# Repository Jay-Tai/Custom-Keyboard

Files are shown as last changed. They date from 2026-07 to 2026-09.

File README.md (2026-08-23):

# The Megaboard
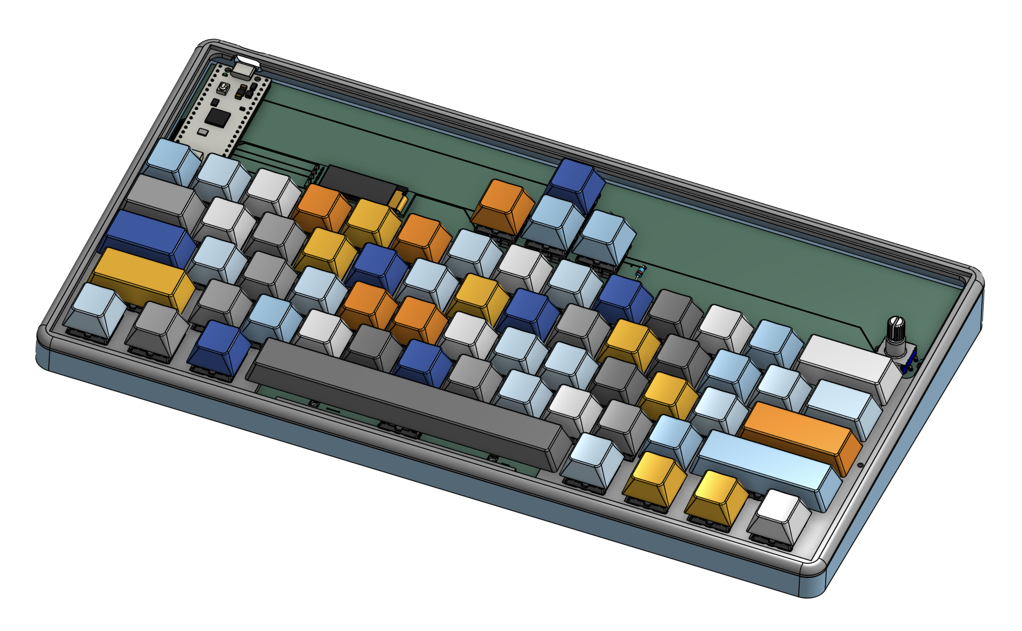
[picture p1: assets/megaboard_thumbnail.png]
The Megaboard!

The megaboard is a custom 60% keyboard that has 65 keys in total, and has many unique functions that truly make this project a one-of-the-kind.

I built this project to participate in [Hack Club's Stardance](http://stardance.hackclub.com/), and fell in love with the development of keyboards very quickly after I started!
## Features
- Amazing 3D printed case
- 0.91" OLED for animations, startup, and for other tools, such as WPM, and Caps Lock
- SK6812 Mini-E LEDs for under-key glow
- EC11 Rotary Encoder to control volume, scroll through pages, or press down to mute/unmute your zoom meeting
- 65 Akko V3 Cream Yellow Pro keys for your satisfying typing experience needs :D (Cheap and sounds like heaven)
- Topographic look all-around (Part of the PCB is exposed)
w
## CAD Model
All the parts of this project fit together using 2 m2.5 screws.
It has 2 seperate printed pirces, one to be the main base, and the other one to cover the electronics.
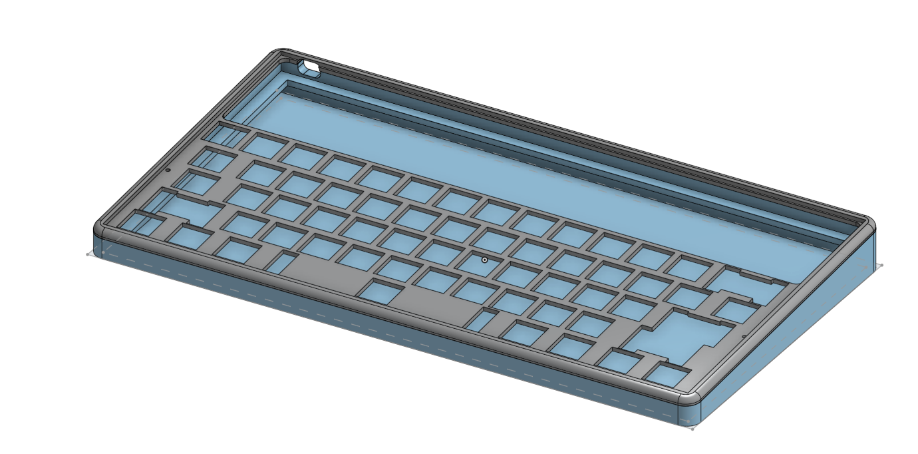
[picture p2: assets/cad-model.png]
Cad Model

Made in OnShape.

## PCB
Here's my PCB! it was made in KiCad. Some footprints and schematics were from marbastlib. I made the silkscreen in Adobe Illustrator.
#### Here is my schematic
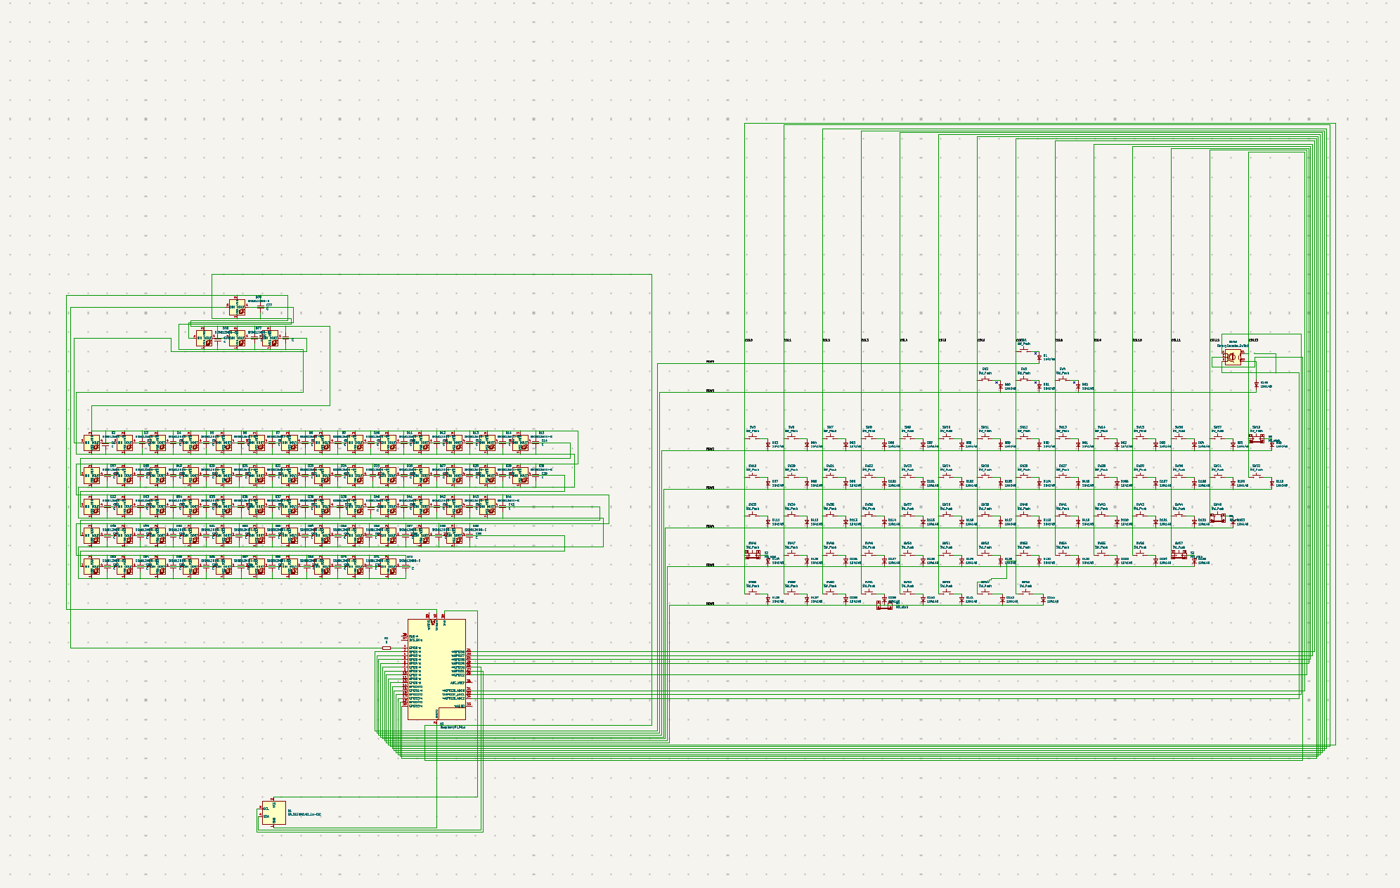
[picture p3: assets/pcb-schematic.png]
My schematic!

#### Here is my PCB
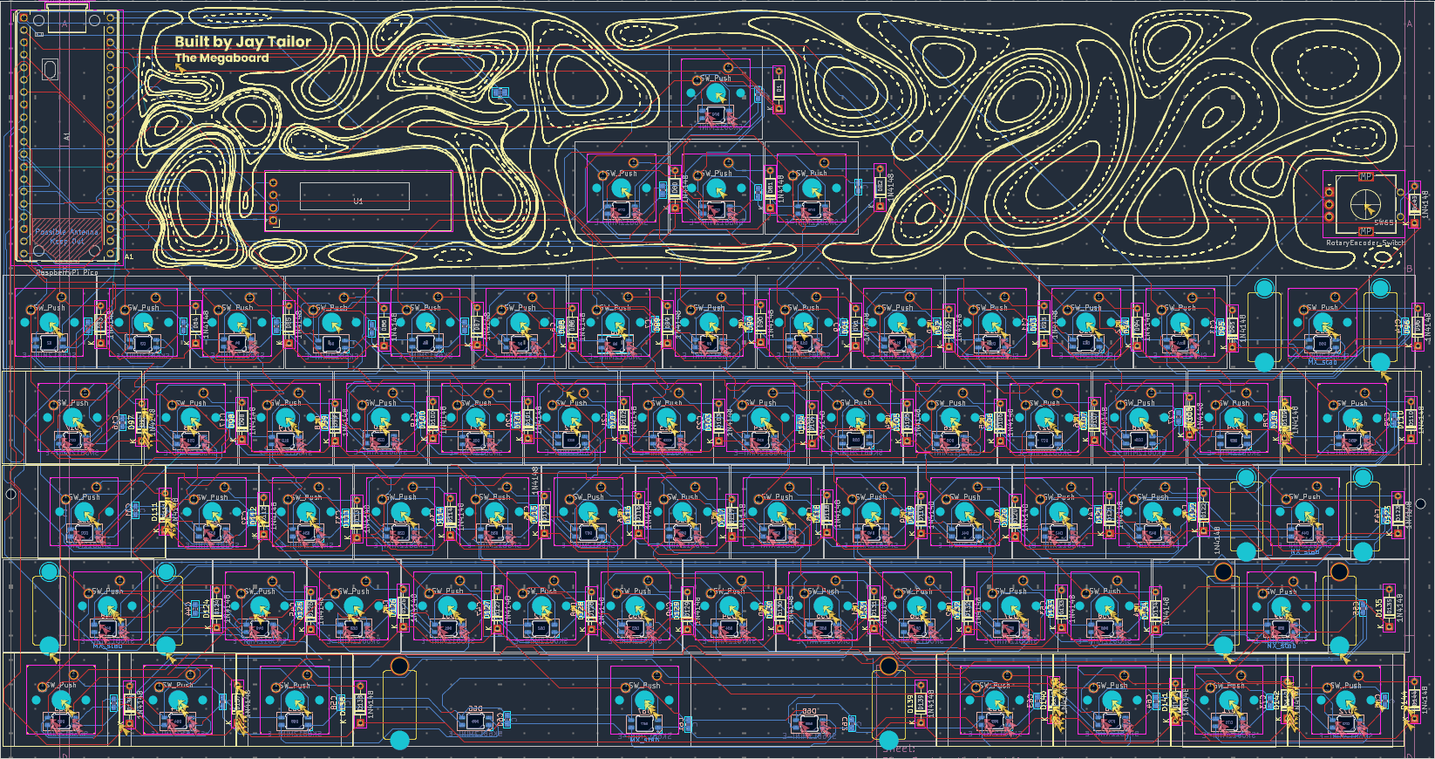
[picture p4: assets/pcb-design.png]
My PCB Design


The PCB has 2 copper layers, and all the parts that are needed are part of the PCB design. I think in retrospect, I should have moved the arrow keys to the bottom of the PCB, instead of it being at the top.

## Firmware overview
This hackpad's firmware has been designed in [QMK](https://qmk.fm/). It is a powerful, yet simple way to design keyboards that have a lot of useful functions!
- The rotary encoder controls the volume of the computer, and when you hold FN, you can scroll. When you press the encoder, it will mute/unmute your zoom call.
- The 65 keys all perform different functions that can be adjusted by simply changing it's function in keymap.c.
- The OLED starts off with a startup animation, and then after, it turns into a cat! Specifically, the Bongocat!! <b>Credits to [nwii's bongocat](https://github.com/nwii/oledbongocat) for the source code!</b>
- All keys have SK6812 Mini-E LEDs beneath them and when you press a key, its LED will light up in a reactive typing way. Take a look [here](https://youtu.be/7f3usatOIKM?t=229)!

I might add more in the future, however, that's it for now!

## BOM
Here is everything that you will need to make the megaboard:
Click [here](https://docs.google.com/spreadsheets/d/1aInlIyzgglzUiH9fcOGwBJfbiqagTssbSa5kihXWXrg/edit?usp=sharing)

## Thank you!
Thank you for taking a look! This was a huge undertaking to make this entire project, and I spent over 50 hours to make this!

Especially, thank you to [Hack Club](https://hackclub.com/) for inspiring me to make this project, and thank you to [nwii's bongocat](https://github.com/nwii/oledbongocat) animation for part of the OLED!

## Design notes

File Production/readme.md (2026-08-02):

# Production files
These are the production files!

The production files are what you need to make your own megaboard!

## Legend
- Top.step is the top part of the shell
- Bottom.step is the bottom part of the shell
- Firmware.uf2 is the firmware of the keyboard!\
- Gerbers.zip is the gerber files to submit to your PCB fab

## Note regarding gerbers
To get the results that the original megaboard looks like, change the PCB color to black.

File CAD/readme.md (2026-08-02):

# CAD

This is my CAD file! It was made on Onshape, and you can see the onshape file [here](https://cad.onshape.com/documents/f72fa77c2f5ca639697d7ad2/w/c788aea54bc0ac7d58691022/e/f66b60b9cfee9ae31c44548f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)

The file that is in this folder is the shell when it is all attached. However, the .step files for the top and bottom can be found under the production folder.

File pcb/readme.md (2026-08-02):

# PCB Files
The following files are all KiCad files. Download all the files and put them in a folder, and put it in KiCad to edit the PCB!

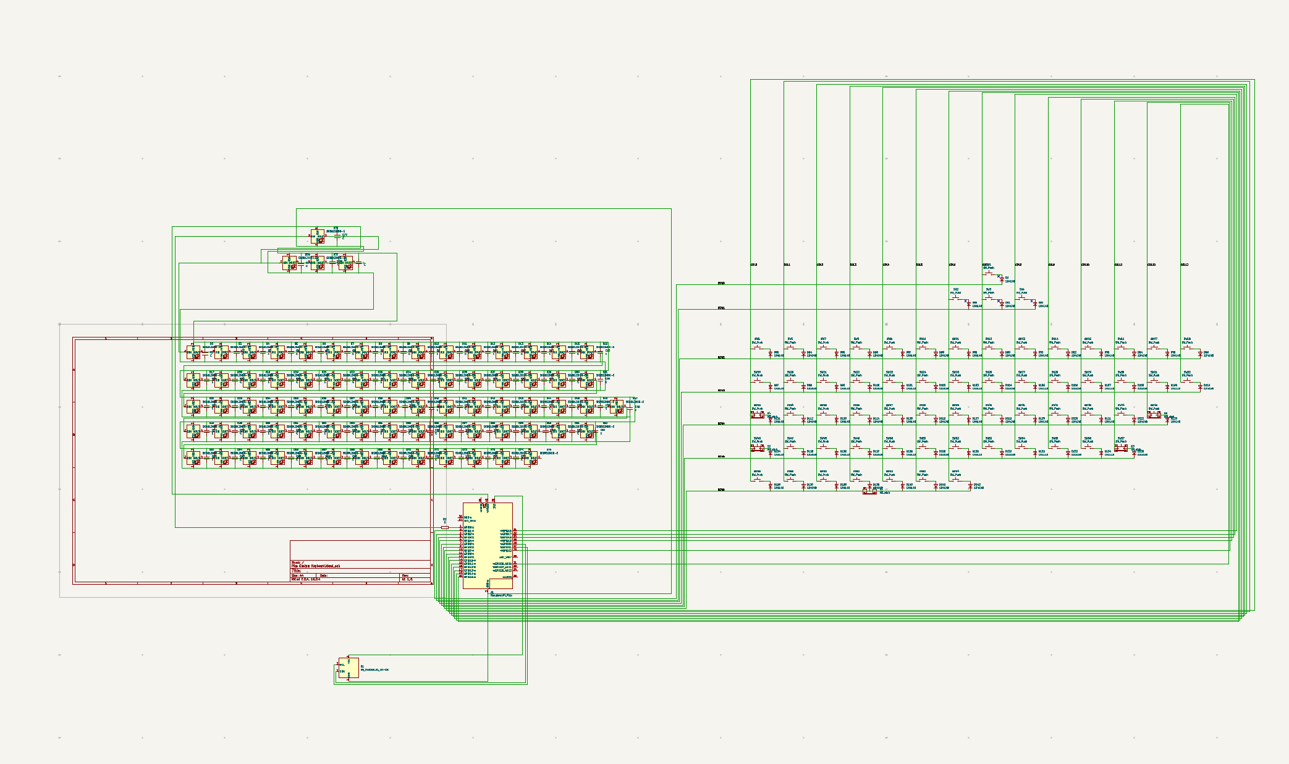
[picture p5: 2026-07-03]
journaling/major updates/schematic/Screenshot.jpg

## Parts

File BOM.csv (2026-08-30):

Item | Description | Quantity | Item Total Price + Tax | Supplier | URL
Akko V3 Cream Yellow Pro | Switches | 2 sets | $43.59 | Akkogear | https://akkogear.eu/checkouts/cn/hWNFC9Zx8n0qdDLtnQizb7BJ/en-ca
Raspberry Pi Pico SC0915 | MCU | 1 | $15.06 | PiShop | https://www.pishop.ca/product/raspberry-pi-pico-non-wireless/?src=raspberrypi
Topographic MX Keycaps | RGB Keycap | 1 set | $11.00 | Aliexpress | https://www.aliexpress.com/item/1005010637419371.html
EC11 Rotary Encoder | Rotary Encoder/Knob | 1 | $2.17 | Digikey | https://www.digikey.ca/en/products/detail/bourns-inc/PEC11R-4220F-S0024/4499660
SSD1306 OLED Display 128x32 | OLED Display | 1 | $1.15 | Aliexpress | https://www.aliexpress.com/item/1005009260655146.html
4x 2u + 1x 6.25u Cherry MX Stabilizer | Key stabilizers | 1 set | $10.02 | Aliexpress | https://www.aliexpress.com/item/1005011961905061.html
Megaboard PCB Printing with JLCPCB | PCB | 5 (Minimum order quantity) | $56.32 | JLCPCB | https://i.ibb.co/LhSh1BdN/Screenshot-2026-08-02-at-12-04-04-PM.png (Screenshot)
SK6812 Mini E-LEDs | RGB LED | 70 | $5.14 | LCSC Electronics | https://www.lcsc.com/product-image/C5149201.html?whichImg=sch
0805 100PF 50V Capacitor | Per-LED Capacitor | 1 | $1.04 | Aliexpress | https://www.aliexpress.com/item/1005007123309391.html
1N4148 Diode | Per-Switch Diode | 65 | $2.11 | Digikey | https://www.digikey.ca/en/products/detail/onsemi/1N4148/458603
M2.5x16mm 50pcs Screw Set | Shell fastener | 1 Set | $7.33 | Aliexpress | https://www.aliexpress.com/item/1005004410362290.html
330 Ohm Resistor | Resistor | 1 | $0.13 | Digikey | https://www.digikey.ca/en/products/detail/stackpole-electronics-inc/CF14JT330R/1741399
Printing Legion Fee - Hack Club 3DP Service | Printing shell | 1 | $15.00 | Hack Club
Digikey International Shipping Fee | Shipping | 1 | $16.14 | Digikey | https://i.ibb.co/r2WyLzsk/Screenshot-2026-08-02-at-12-36-13-PM.png (Screenshot)
Grand total | $186.19 |  | Please note that all costs are listed in US Dollars (USD), and all shipping costs are included in the item price, unless specified when bolded, in which, the shipping costs are italicized

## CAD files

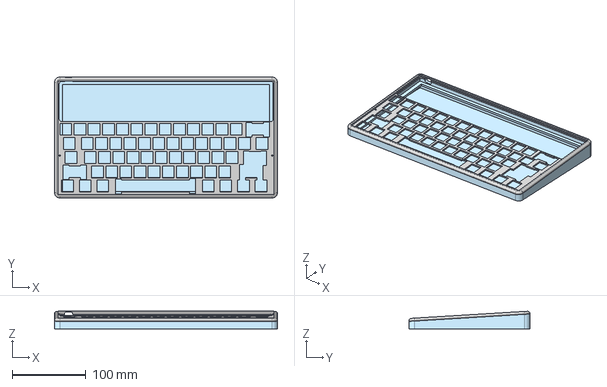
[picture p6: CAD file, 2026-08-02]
CAD/shell.step
302.4 x 164.0 x 23.8 mm

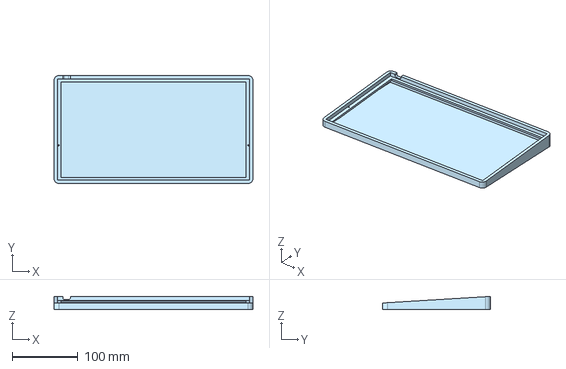
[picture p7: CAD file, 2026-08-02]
Production/Bottom.step
302.4 x 164.0 x 20.0 mm

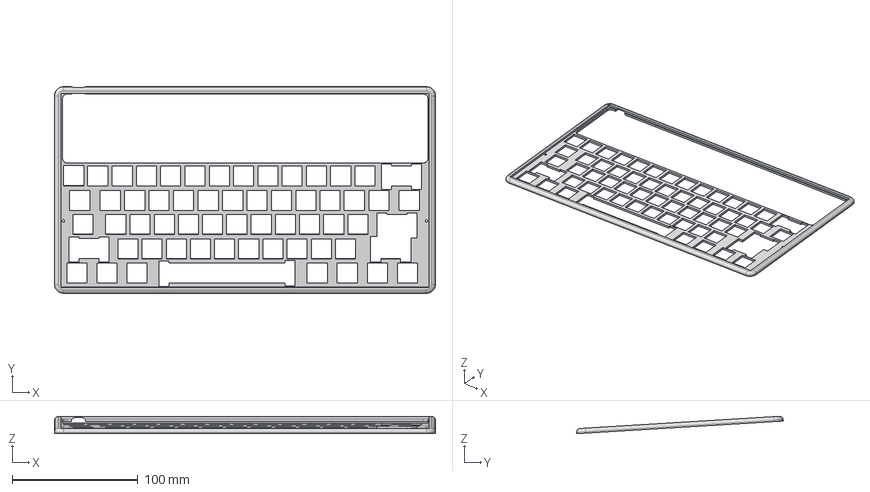
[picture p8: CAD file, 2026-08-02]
Production/Top.step
302.4 x 164.0 x 13.8 mm

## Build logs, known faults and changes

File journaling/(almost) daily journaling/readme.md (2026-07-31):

# My (Almost) daily journaling
This is the journaling that I have been keeping track of!

Please note that <b>my journal entries were originally stored on fallout, and have been imported since</b>.

The folder names are the dates of the journal entries.

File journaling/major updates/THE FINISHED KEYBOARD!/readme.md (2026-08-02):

# The final keyboard! (WOOOOOO)
The keyboard is finally finished!

I spent around 60 hours on it (Some time hasn't been logged as I forgot to click record, however, over 50 hours have been logged), and it is finally finished!

Here is what the keyboard will look like when I make it:
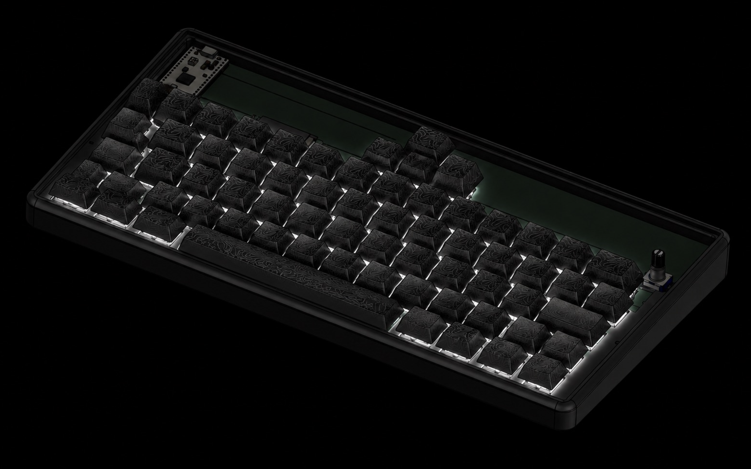
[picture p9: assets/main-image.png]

Please note that the image is an AI-Generated image, but is accurate on what the actual keyboard will look like (Only the key labels and the top PCB silkscreen is missing)

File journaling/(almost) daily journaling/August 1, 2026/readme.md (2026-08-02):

<p><b>Started the BOM!</b></p>
<p><i>1 hour and 45 mintues logged</i></p>

Today, I started my BOM! I finished a good portion of it, and I am going to finish the rest tomorrow.

When I was looking at JLCPCB, the actual keyboard PCB turned out really nice in black! Take a look :)

I am going to get it in black, as part of the PCB is going to be exposed (Right before the topographic silkscreen starts to show)

See you tomorrow!

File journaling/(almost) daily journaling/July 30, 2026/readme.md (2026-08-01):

<p><b>Today was a somewhat productive day!</b></p>
<p><i>1 hour and 3 minutes logged</i></p>

Today was a somewhat productive day!
I managed to program the entire startup screen, and I managed to import the bongo cat's frames.


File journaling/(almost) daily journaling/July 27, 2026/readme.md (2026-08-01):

Today, I open-sourced the keyboard bongo and also made my loading screen for my OLED into the bitmaps!
Doesn't it look so cool?


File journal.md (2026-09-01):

# July 3, 2026
<p><b>My KiCad Schematic!</b></p>
<p><i>4 hours and 27 minutes logged</i></p>
<p>(Yes, it was all done in a day haha)</p>

The schematic includes all the components of my keyboard!
The keyboard includes all the correct wiring for the backlights, the switches, the Display, and the Rotary Encoder that is going to be part of the final keyboard.
I acutally got really lucky with the microcontroller - I had JUST ENOUGH ports to house all the different pins that everything in my keyboard requires.

<i>Take a look at the final shematic!</i>
<br/>
The final schematic!

Watch the timelapse here:
https://f8d710a55cb9b516d88635f103c2c9f2.r2.cloudflarestorage.com/collapse/timelapses/5871cd09-b832-4ddf-aae9-c32493282611/timelapse.mp4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

# July 4, 2026
<p><b>Assigning footprints!</b></p>
<p><i>2 hours and 3 minutes logged</i></p>

Today was a bit of a busy day for me. However, for my custom keyboard, I still managed to work on assigning my footprints!
I forgot to record part of it. Sorry! :P
I faced a bit of an error where KiCad kept on crashing every single time I tried opening the "Assign Footprints" window. I  spent around 2 hours on that!



# July 5, 2026
<p><b>Electric component layout</b></p>
<p><i>2 hours and 2 minutes logged</i></p>

Today, I worked on figuring out electrical component layout, along with placing the arrow keys + top row of my keyboard (Along with all of its electrical components, such as a Capacitor!)
Take a look at the image!



# July 6, 2026
<p><b>Finishing layout + starting wiring</b></p>
<p><i>3 hours and 32 minutes logged</i></p>

Today, I finished the layout of my entire project and started wiring! I finished the power and GND of all LEDs, and I am working on DIN and DOUT!


# July 7, 2026
<p><b>Finished wiring!</b></p>
<p><i>3 hours and 5 minutes logged</i></p>

Today, I finished up all of the wiring for my project, fixed any errors, and also finished 90% of the wiring for the switches!
Here's a quick photo of it! :D


Tomorrow, I am going to finish my PCB, and start the case!
IM SO EXCITEDDDD

# July 8, 2026
<p><b>Small update</b></p>
<p><i>1 hour and 5 minutes logged</i></p>

Today was a bit of just a small progress day. I finished the wiring, and fixed an error with my rotary encoder.



I also learnt how to make silkscreens!

# July 9, 2026
<p><b>Keyboard Silkscreen Work</b></p>
<p><i>1 hour and 3 minutes logged</i></p>

Today, I worked on the keyboard's Silkscreen! I am making a topographic layer, and I finished the rough idea of how it will look like!
Tomorrow, I will be cleaning up the effect, and then adding it to my project!
This is what the silkscreen looks like so far! :D



# July 11, 2026
<p><b>Finished the PCB!</b></p>
<p><i>5 hours and 36 minutes logged</i></p>

Today, I finished my PCB!
I worked on the silkscreen and made that the rest of the PCB was in function



# July 12, 2026
<p><b>Starting the CAD!</b></p>
<p><i>1 hour and 17 minutes logged</i></p>

Today, I started the CAD! I didn't get far, as I was getting very distracted, and still getting in the jist of things. In addition, I also wasn't at home or at my computer for a long portion of today.


# July 13, 2026
<p><b>Fixing my PCB</b></p>
<p><i>1 hour and 45 minutes logged</i></p>

Today, I made a HUGE realization: I placed the LEDs on the wrong side of the PCB, meaning that all the LEDs need to be rewired! This is me trying to figure it out :P
How cool is this silkscreen tho? :D


# July 15, 2026
<p><b>Fixing wiring</b></p>
<p><i>1 hour and 3 minutes logged</i></p>

Today, I ended up deleting all of the previous vias I made for my PCB's lights, and ended up starting all over again. Here is a look!



# July 16, 2026
<p><b>Big breakthrough</b></p>
<p><i>1 hour and 14 minutes logged</i></p>

Today, I had to clear out all of my work again, but I learnt what vias are, and how to make them, along with making a VCC plane to help me finally finish these LEDs! I will be doing that tomorrow.
Here's a look at one of my vias that I am going to be connecting to a plane from a capacitor.



# July 17, 2026
<p><b>Finished the PCB!</b></p>
<p><i>1 hour and 4 minutes logged</i></p>

Today, I finished up my PCB! I made a ground plane, and I used the Vias that I learnt about yesterday to make clean wiring for my keyboard.
Here's what it looks like!



(The random background is the ground plane)

# July 18, 2026
<p><b>Started the CAD!</b></p>
<p><i>1 hour and 9 minutes logged</i></p>

Today, I started my CAD! I made the main base, along with a spot to put in my PCB. here's what it looks like so far! :D


# July 19, 2026
<p><b>Finished the keyboard shell!</b></p>
<p><i>1 hour and 40 minutes logged</i></p>

Today, I finished up the shell for the keyboard! This was really fun to make, and it took ~2.5 hours to make the entire thing.


# July 20, 2026
<p><b>Starting the firmware!</b></p>
<p><i>1 hour and 21 minutes logged</i></p>

Today, I started the firmware for my keyboard! I laid out all of the functions of the keys, and I programmed all of them. I also created the macro for the mute/unmute function of the rotary encoder wheToday, I started the firmware for my keyboard! I laid out all of the functions of the keys, and I programmed all of them. I also created the macro for the mute/unmute function of the rotary encoder when I press it in meetings.
Tomorrow, I will be programming the lights and the screen. From there, I am going to do the final touches, create the BOM, and then end a chapter!
Here is the code so far!


# July 21, 2026
<p><b>2nd day of my firmware!</b></p>
<p><i>1 hour and 41 minutes logged</i></p>

Today, I was writing my firmware again!
For some reason, it didn't save my work yesterday, so I redid it (For 25 minutes), and I finished the encoder and configured the lights so far!
Excited for tomorrow!


# July 22, 2026
<p><b>Transition day to rust</b></p>
<p><i>1 hour and 15 minutes logged</i></p>

Today was more of a transition day. I still worked on the firmware, but I was making the transfer from cloud RMK to rust. This meant that I had to spend time adapting my firmware from cloud to rust. That was my day today!


# July 24, 2026
<p><b>Finshing the keyboard keymap</b></p>
<p><i>1 hour and 6 minutes logged</i></p>

Today, I finished the keymap of my keyboard, and I am onto the rotary encoder! However, I am constantly facing errors, and I am pushing through that!


# July 25, 2026
<p><b>Biggest leap in firmware</b></p>
<p><i>2 hours and 26 minutes logged</i></p>

Today was the biggest leap in my firmware so far.
I found that RMK was not worth fiddling around with for so long. It's better to get another firmware that I am more used to. This is why I used QMK.
With QMK, it made it really easy to get the reactive typing feeling that I wanted. Here's a quick idea of how it will look like: https://youtu.be/7f3usatOIKM?t=229
With that idea, I switched to QMK, added all that I had before, and made the reactive typing interface! I'm really proud of the result!


# July 26, 2026
<p><b>LCD Design!</b></p>
<p><i>1 hour and 55 minutes logged</i></p>

Today, I mainly explored how to design my LCD display. I designed a concept of a loading bar when the keyboard is first plugged in (see image below), and I might open source the popular keyboard bongo!


# July 27, 2026
Today, I open-sourced the keyboard bongo and also made my loading screen for my OLED into the bitmaps!
Doesn't it look so cool?


# July 29, 2026
<p><b>JSON + Starting OLED!</b></p>
<p><i>1 hour and 6 minutes logged</i></p>

Today, I worked on my JSON, and also started the coding part for my OLED! This was a bit of a slow day, though :P


# July 30, 2026
<p><b>Today was a somewhat productive day!</b></p>
<p><i>1 hour and 3 minutes logged</i></p>

Today was a somewhat productive day!
I managed to program the entire startup screen, and I managed to import the bongo cat's frames.


# July 31, 2026
<p><b>LETS GOOOOOOOO</b></p>
<p><i>2 hours and 4 minutes logged</i></p>

Today, I FINALLY finished the code of the firmware! I went through a ton of bugs, and the code finally compiled!



From there, I also added all of the journal logs finally into my GitHub repo!

# August 1, 2026
<p><b>Started the BOM!</b></p>
<p><i>1 hour and 45 mintues logged</i></p>

Today, I started my BOM! I finished a good portion of it, and I am going to finish the rest tomorrow.

When I was looking at JLCPCB, the actual keyboard PCB turned out really nice in black! Take a look :)

I am going to get it in black, as part of the PCB is going to be exposed (Right before the topographic silkscreen starts to show)

See you tomorrow!

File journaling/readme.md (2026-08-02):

# Total time spent: 50 hours and 21 minutes logged
Please note that all of the tiem that I spent working on this project hasn't been logged. Part of the time that I spent on this I forgot to record, and with the lost logged time, I spent around 60-65 hours on this.

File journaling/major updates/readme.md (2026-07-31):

# Major Updates

Alongside with all of the journaling that I have done for this project, I have also added the most major updates! Take a look at the folders! :D

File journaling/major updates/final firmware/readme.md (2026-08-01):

# Let's GOOOOO
Today, I finished the firmware for my project! It's on QMK.

It took a long time, (The longest component of this entire project), but now that the last component is done, I am more motivated than ever to get the last small parts of the project done!
Noice

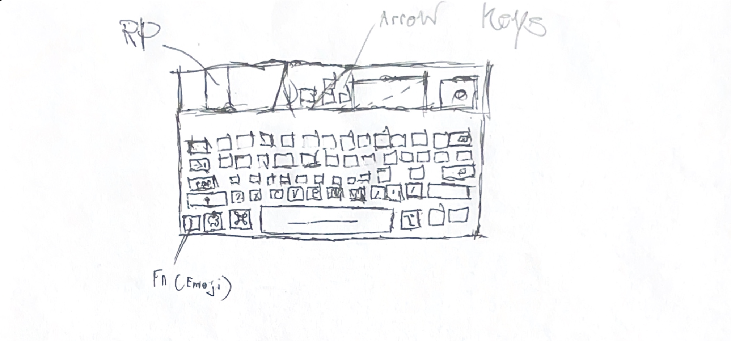
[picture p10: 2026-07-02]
journaling/major updates/sketching/Final Sketch.png

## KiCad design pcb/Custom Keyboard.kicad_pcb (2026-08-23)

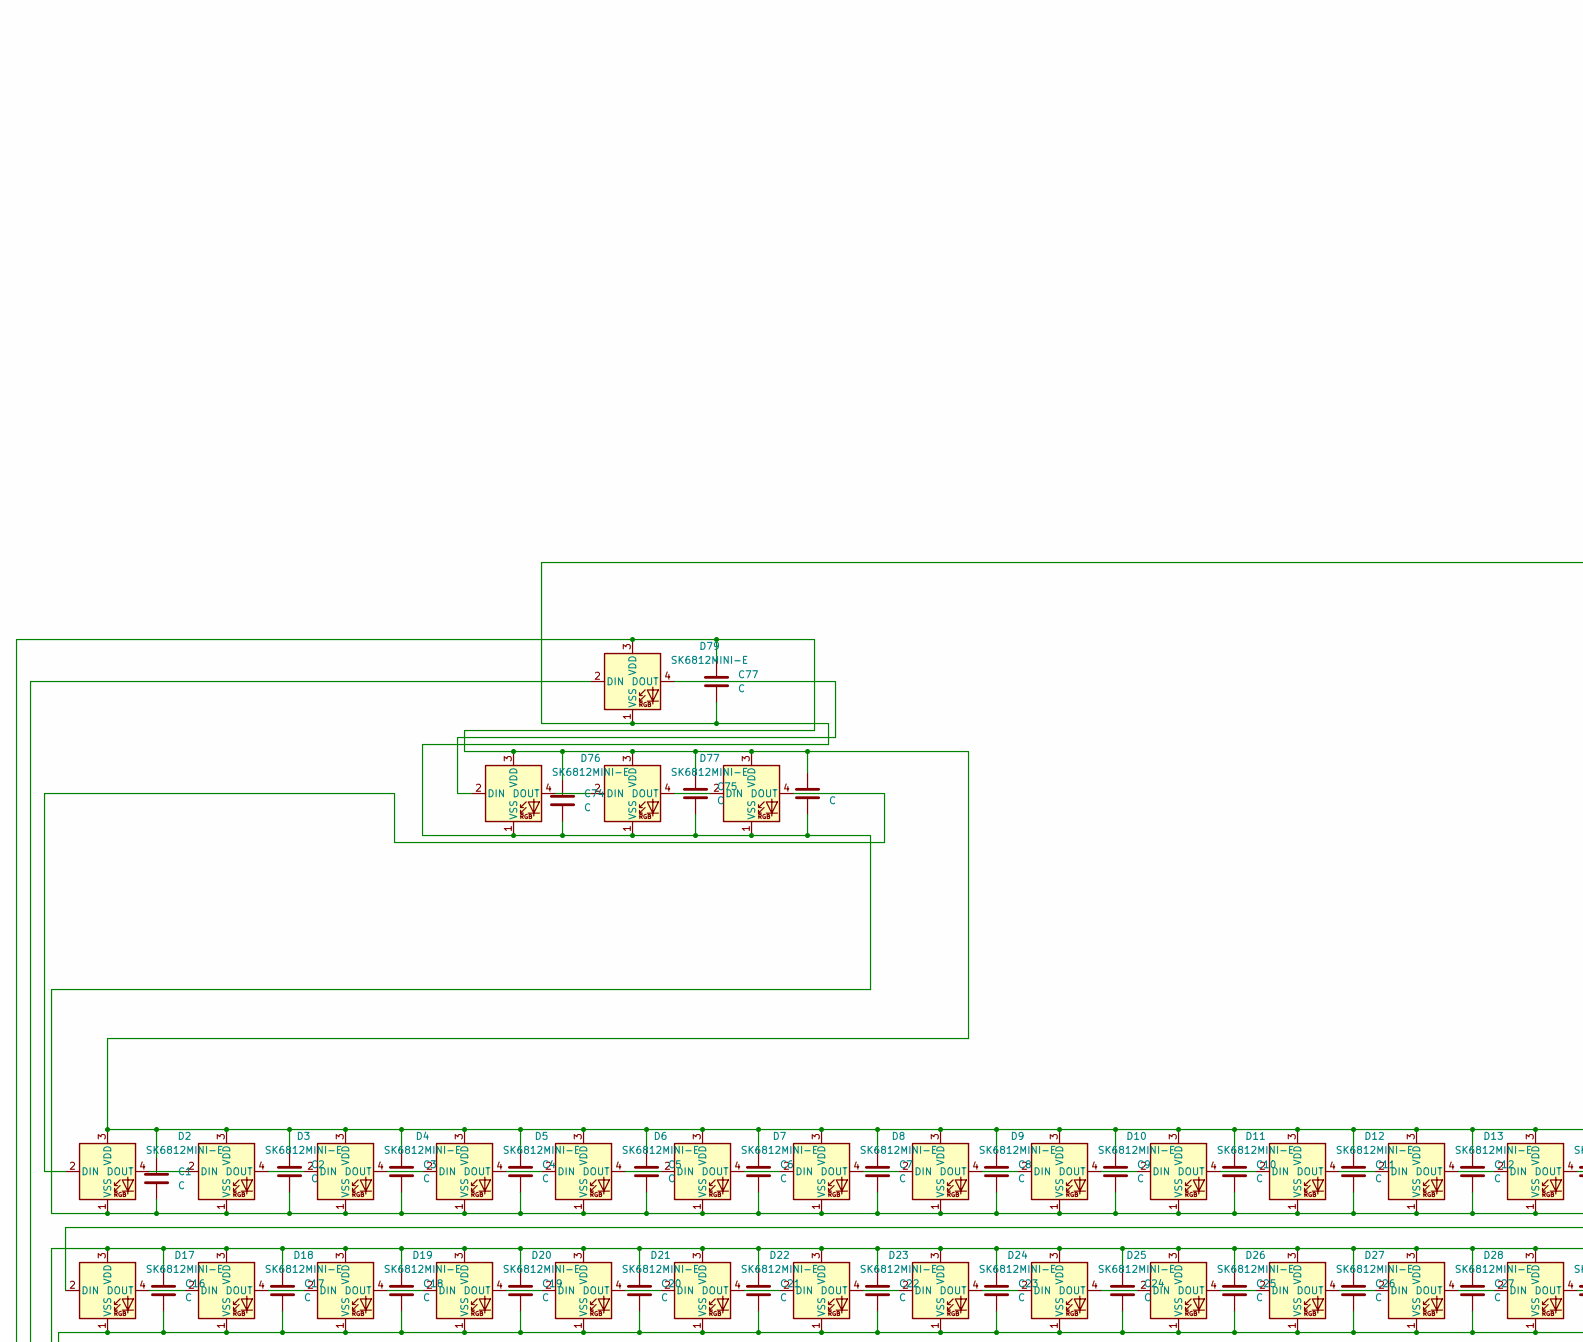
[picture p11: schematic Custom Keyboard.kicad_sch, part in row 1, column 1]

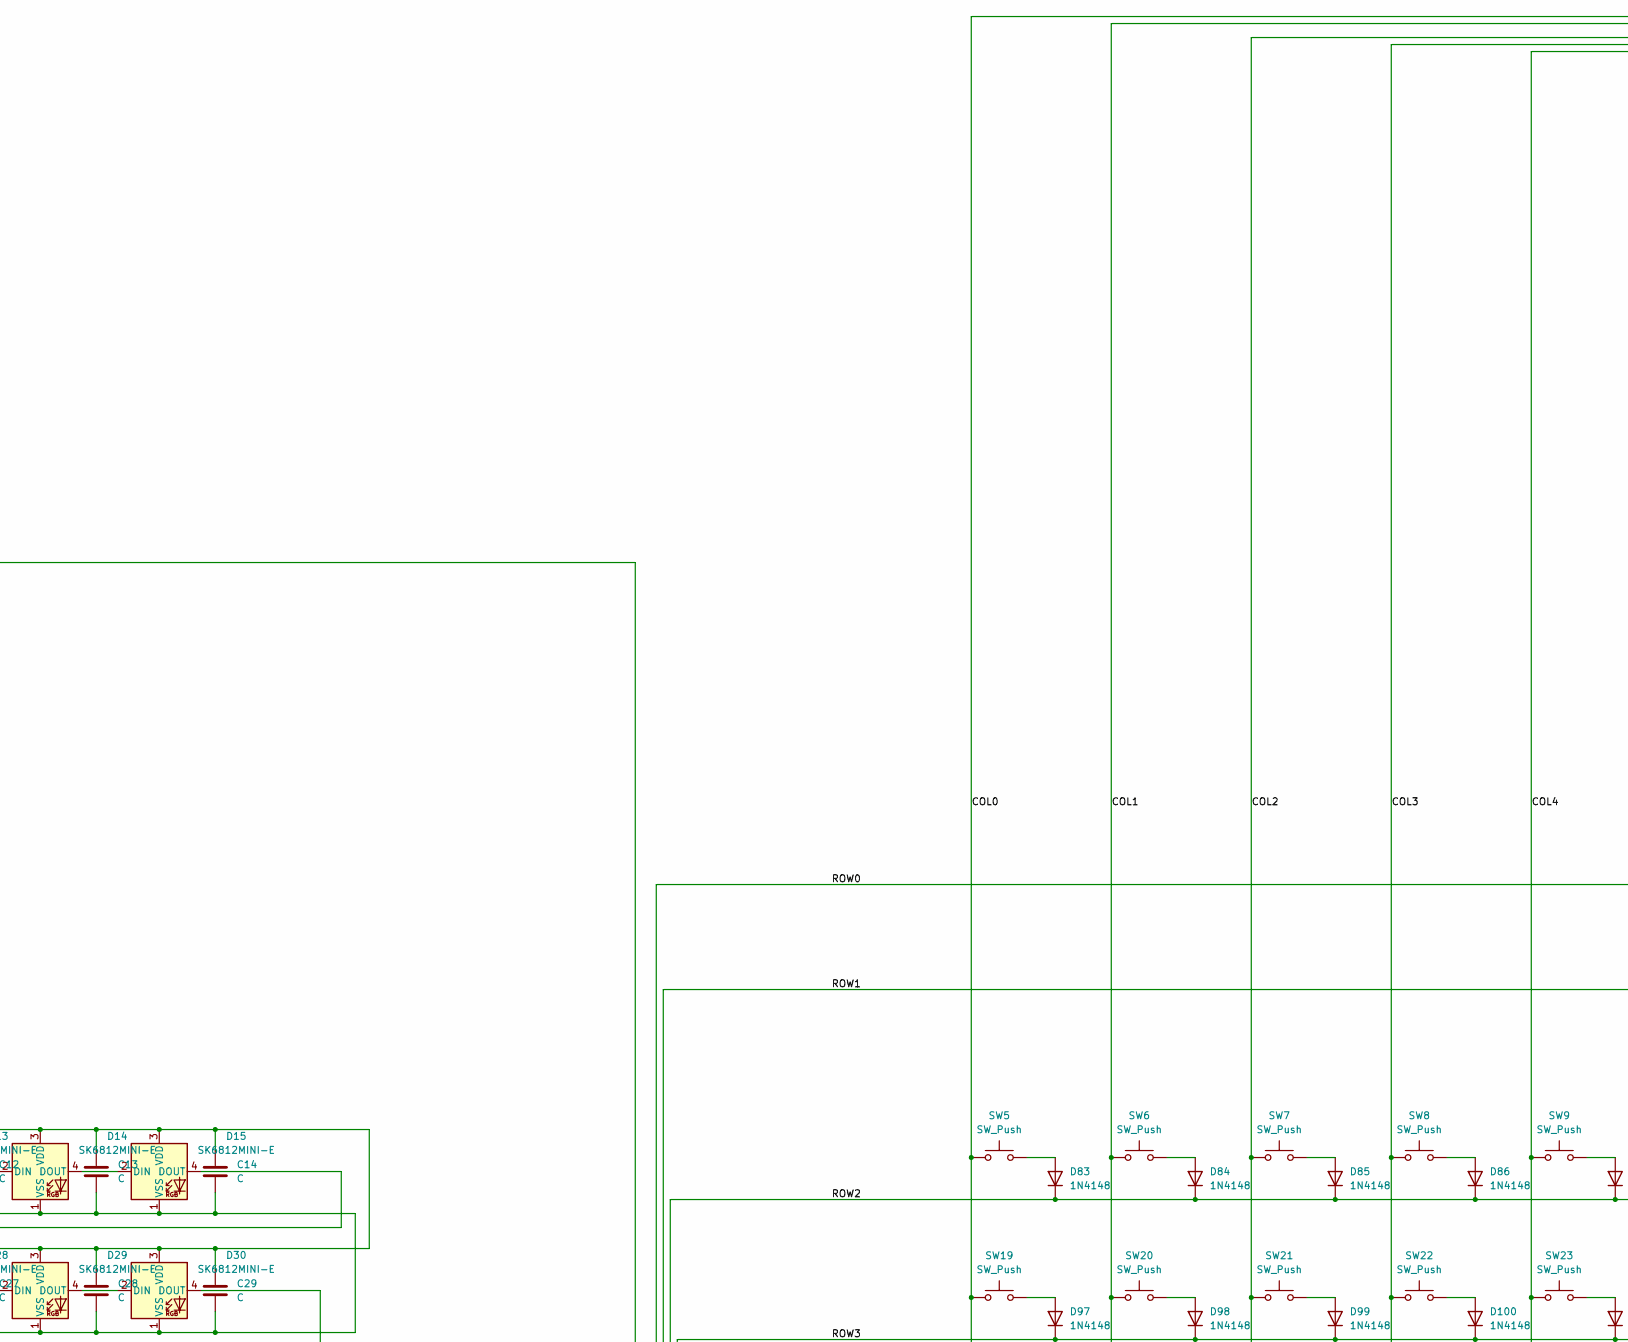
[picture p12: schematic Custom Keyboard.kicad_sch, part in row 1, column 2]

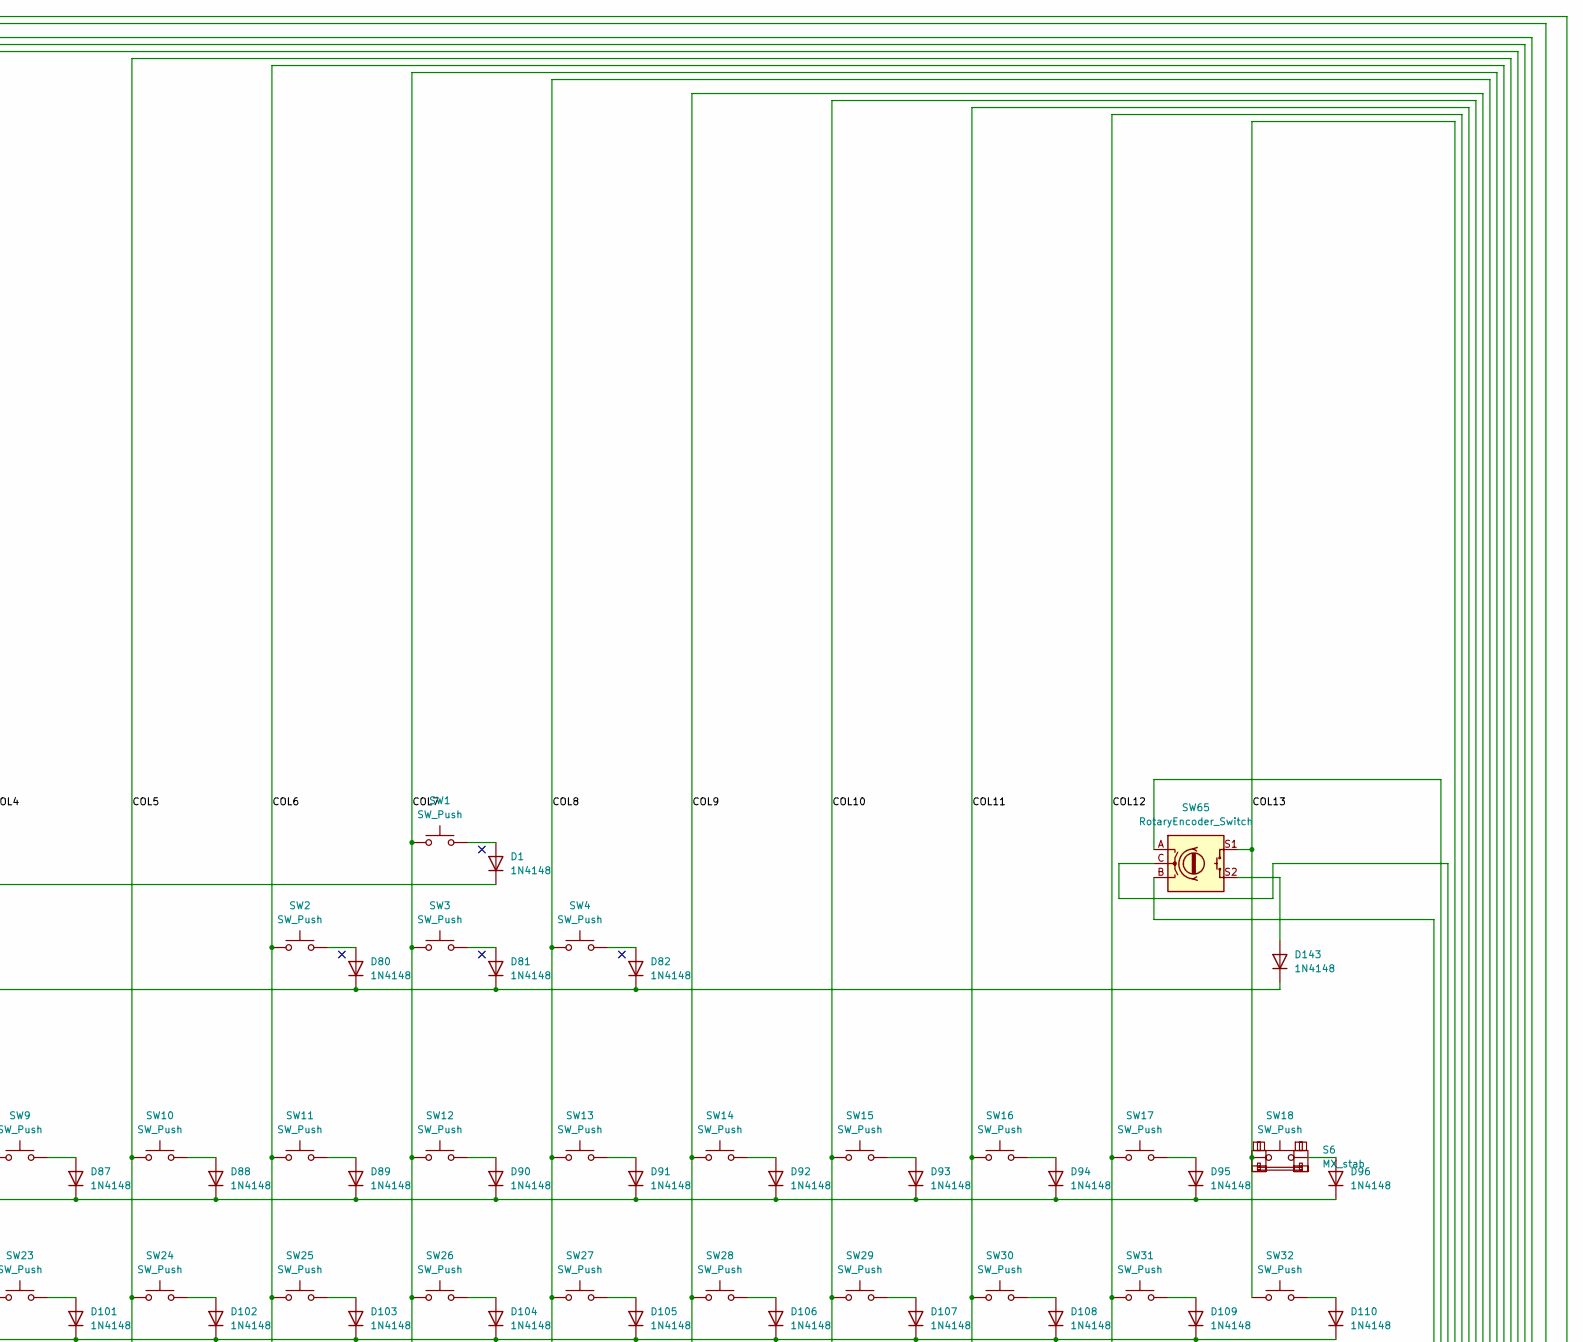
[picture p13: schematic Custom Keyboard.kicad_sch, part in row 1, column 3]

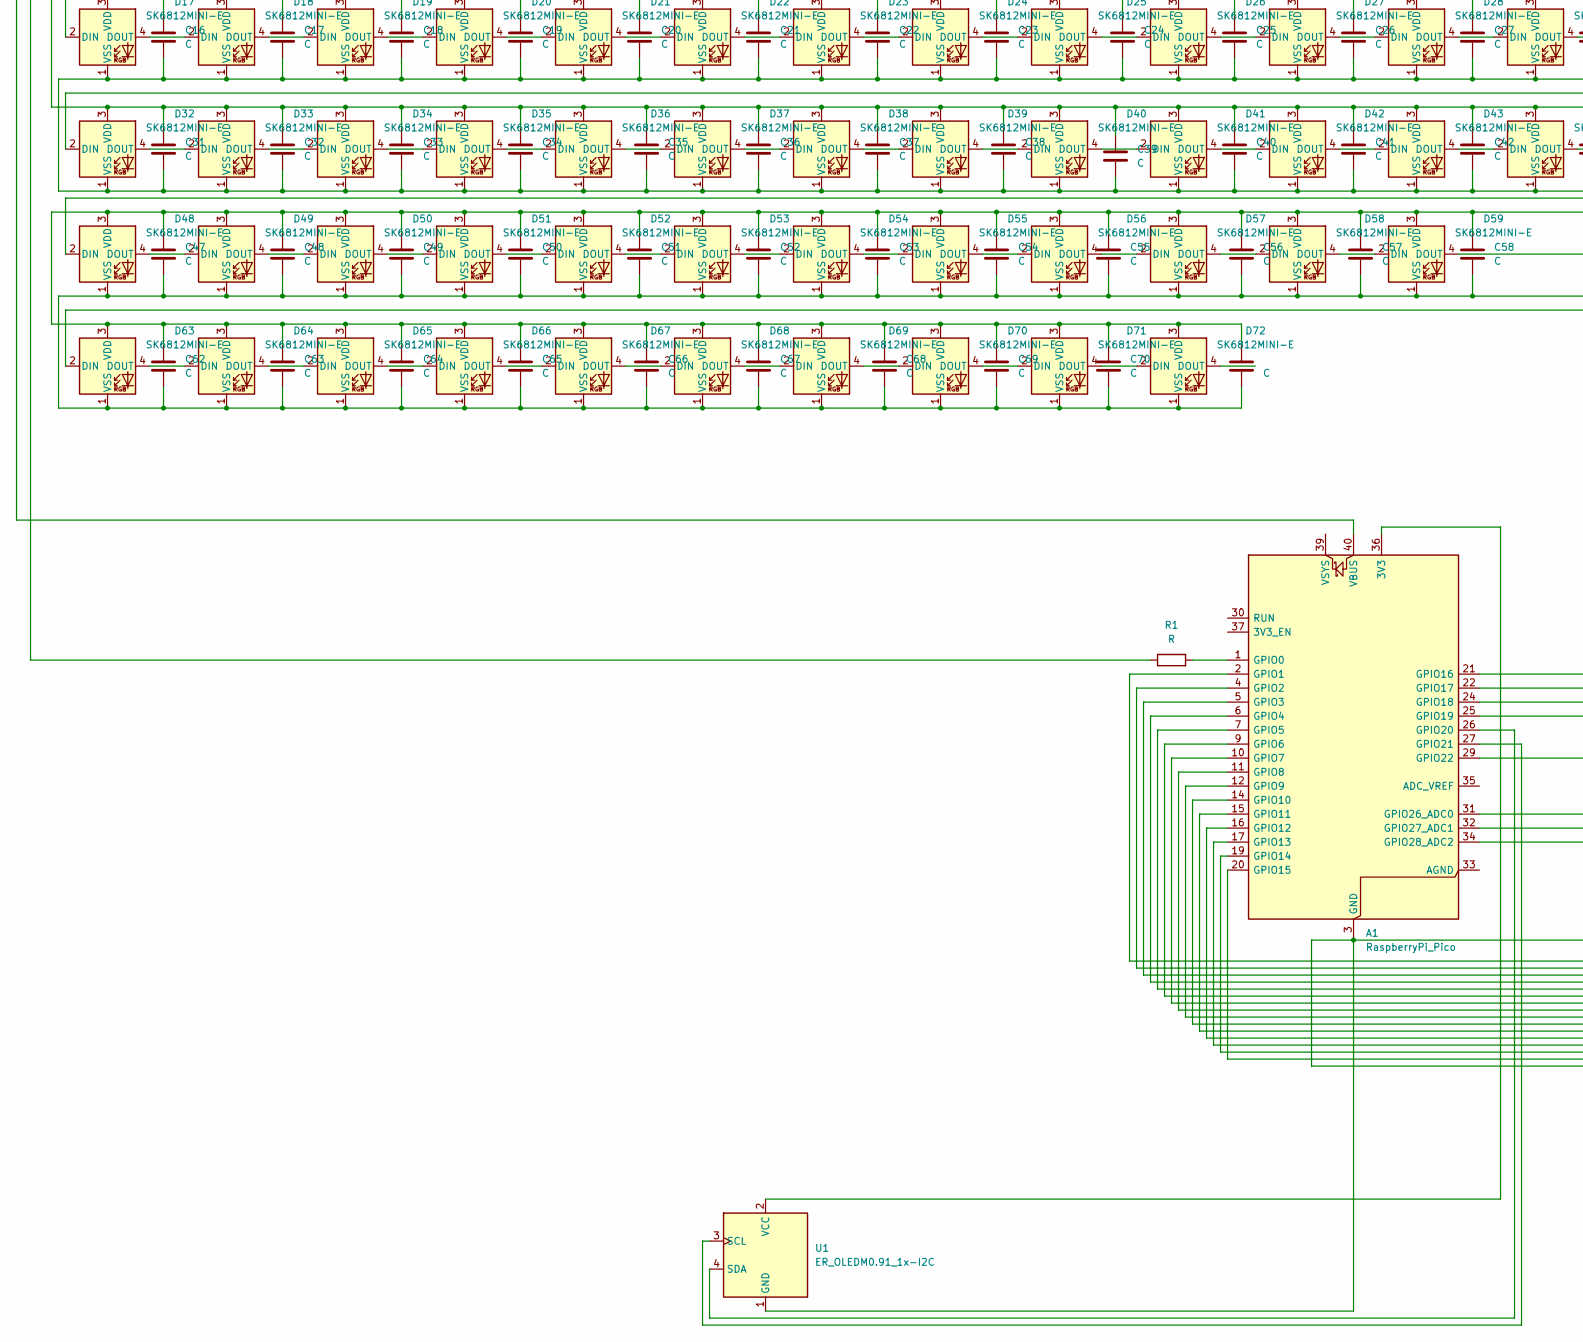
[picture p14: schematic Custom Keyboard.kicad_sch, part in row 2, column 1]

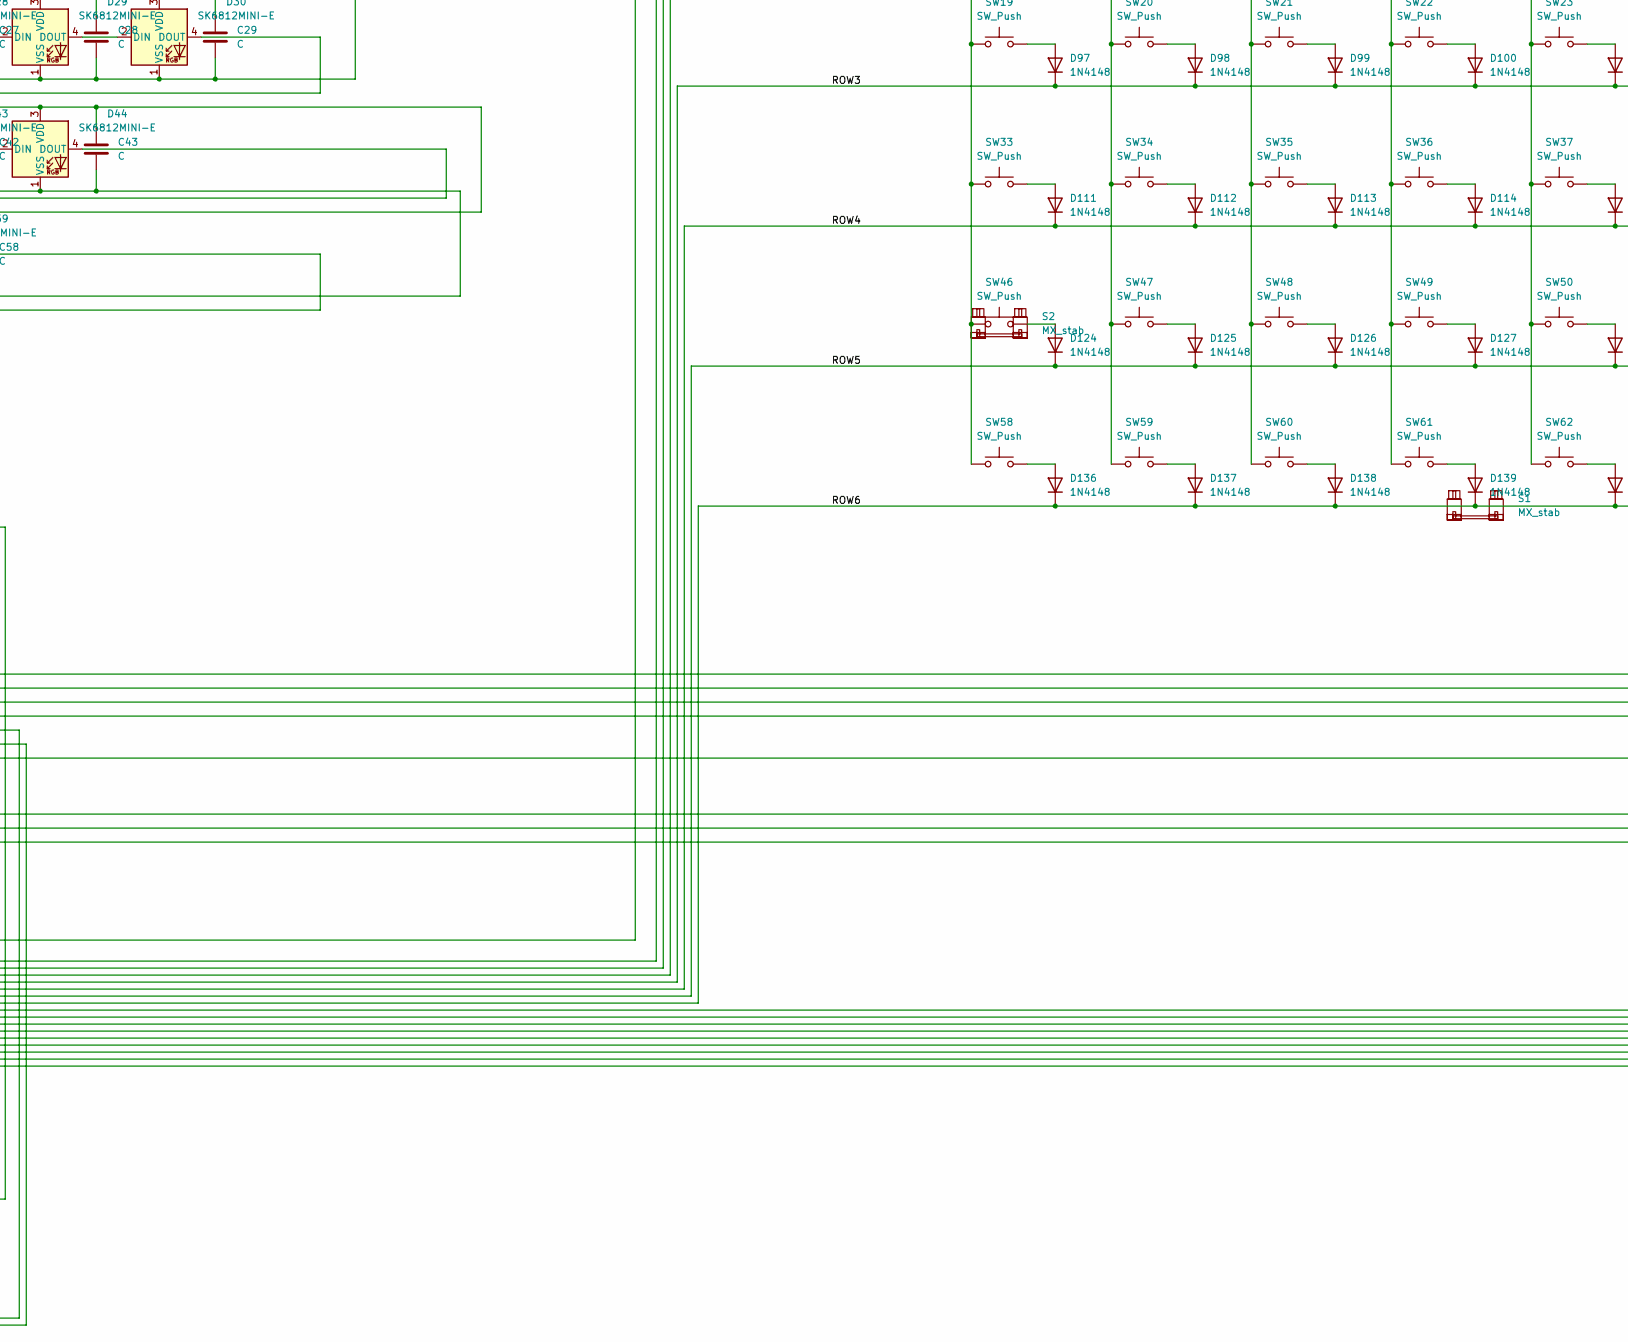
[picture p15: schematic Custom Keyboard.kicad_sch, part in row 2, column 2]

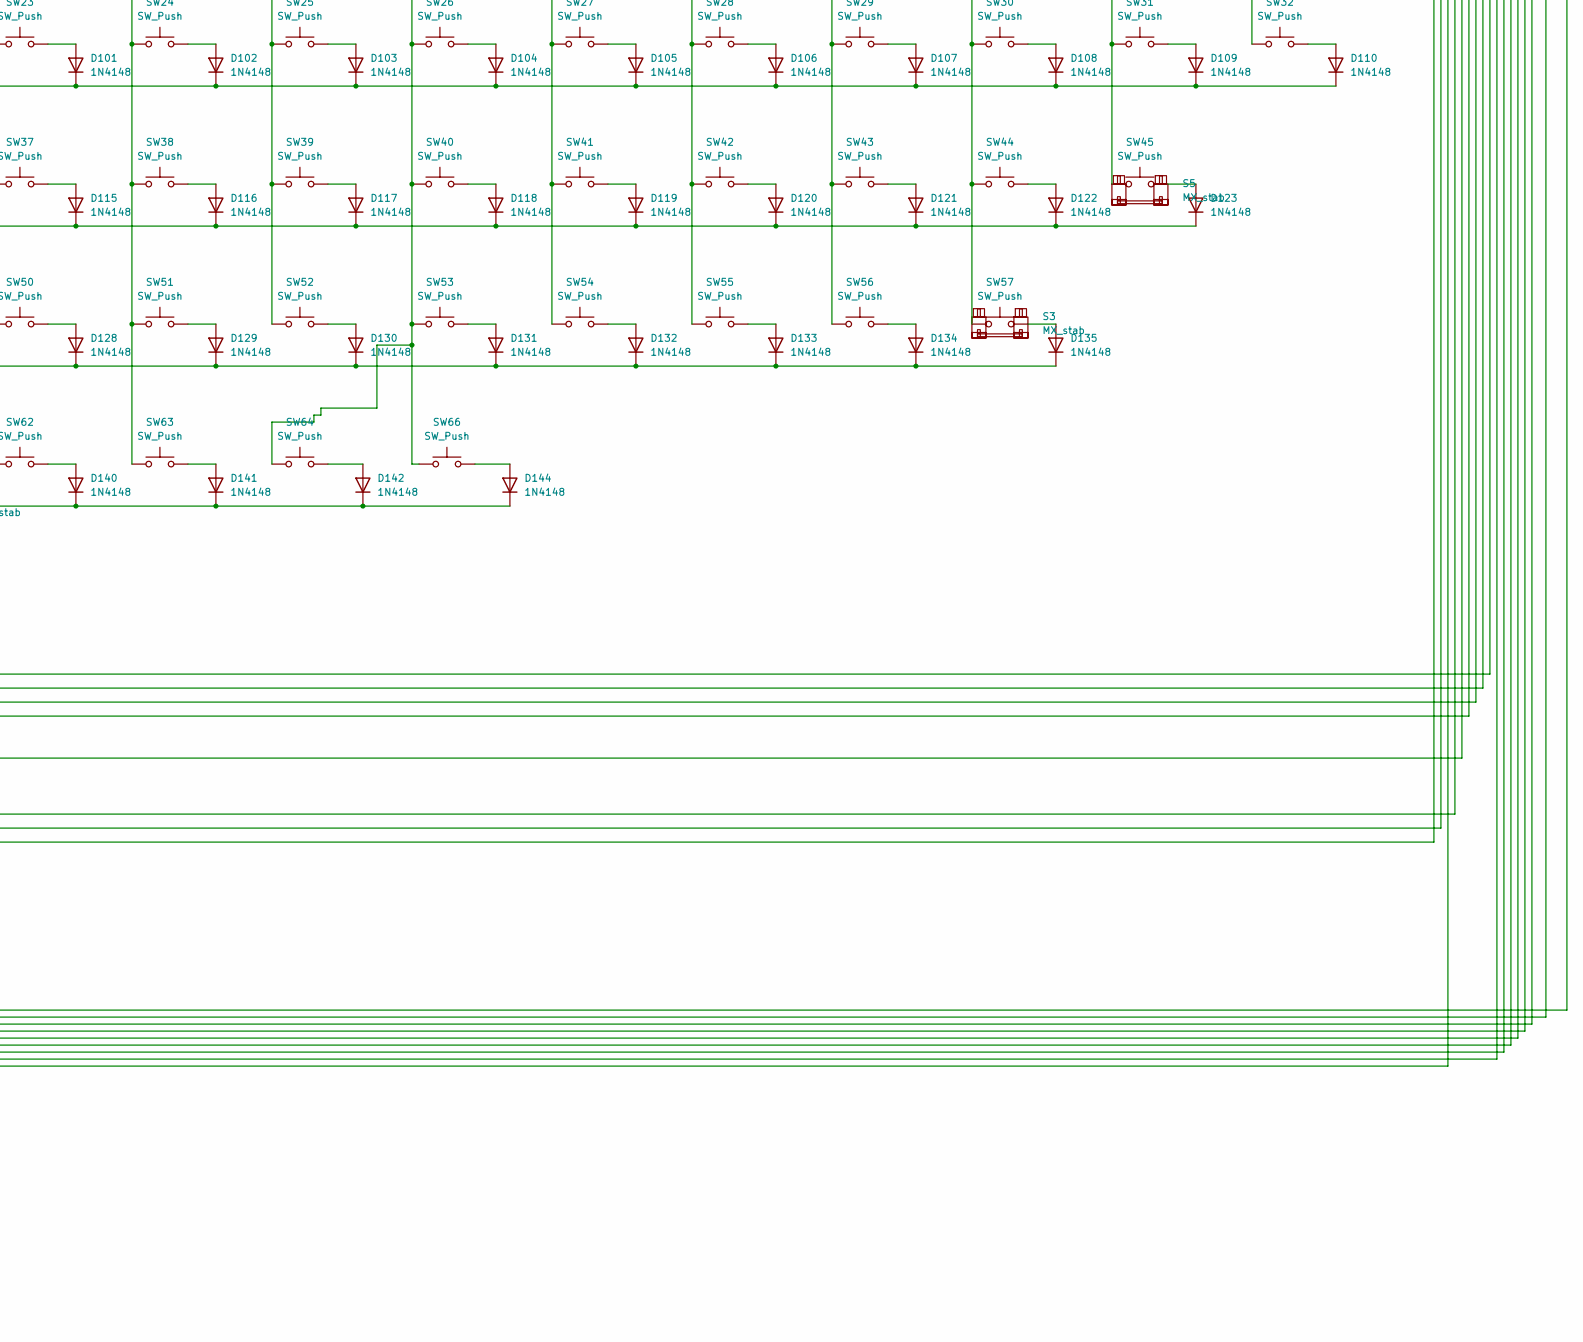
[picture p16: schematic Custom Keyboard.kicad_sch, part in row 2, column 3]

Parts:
A1: RaspberryPi_Pico; RaspberryPi_Pico_Common_THT
C1, C2, C3, C4, C5, C6, C7, C8, C9, C10, C11, C12, C13, C14, C16, C17, C18, C19, C20, C21, C22, C23, C24, C25, C26, C27, C28, C29, C31, C32, C33, C34, C35, C36, C37, C38, C39, C40, C41, C42, C43, C47, C48, C49, C50, C51, C52, C53, C54, C55, C56, C57, C58, C62, C63, C64, C65, C66, C67, C68, C69, C70, C71, C74, C75, C76, C77: C; C_0603_1608Metric_Pad1.08x0.95mm_HandSolder
D1, D80, D81, D82, D83, D84, D85, D86, D87, D88, D89, D90, D91, D92, D93, D94, D95, D96, D97, D98, D99, D100, D101, D102, D103, D104, D105, D106, D107, D108, D109, D110, D111, D112, D113, D114, D115, D116, D117, D118, D119, D120, D121, D122, D123, D124, D125, D126, D127, D128, D129, D130, D131, D132, D133, D134, D135, D136, D137, D138, D139, D140, D141, D142, D143, D144: 1N4148; D_DO-35_SOD27_P7.62mm_Horizontal
D2, D3, D4, D5, D6, D7, D8, D9, D10, D11, D12, D13, D14, D15, D17, D18, D19, D20, D21, D22, D23, D24, D25, D26, D27, D28, D29, D30, D32, D33, D34, D35, D36, D37, D38, D39, D40, D41, D42, D43, D44, D48, D49, D50, D51, D52, D53, D54, D55, D56, D57, D58, D59, D63, D64, D65, D66, D67, D68, D69, D70, D71, D72, D76, D77, D78, D79: SK6812MINI-E; LED_SK6812MINI-E_3.2x2.8mm_P1.5mm_ReverseMount
R1: R; R_0805_2012Metric
S1: MX_stab; STAB_MX_P_6.25u
S2, S5: MX_stab; STAB_MX_2.25u
S3: MX_stab; STAB_MX_P_2.75u
S6: MX_stab; STAB_MX_2u
SW1, SW2, SW3, SW4, SW5, SW6, SW7, SW8, SW9, SW10, SW11, SW12, SW13, SW14, SW15, SW16, SW17, SW18, SW19, SW20, SW21, SW22, SW23, SW24, SW25, SW26, SW27, SW28, SW29, SW30, SW31, SW32, SW33, SW34, SW35, SW36, SW37, SW38, SW39, SW40, SW41, SW42, SW43, SW44, SW45, SW46, SW47, SW48, SW49, SW50, SW51, SW52, SW53, SW54, SW55, SW56, SW57, SW58, SW59, SW60, SW61, SW62, SW63, SW64, SW66: SW_Push; SW_MX_1u
SW65: RotaryEncoder_Switch; RotaryEncoder_Alps_EC11E_Vertical_H20mm
U1: ER_OLEDM0.91_1x-I2C

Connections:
/COL0: A1.11 (GPIO8), SW5.1, SW19.1, SW33.1, SW46.1, SW58.1
/COL1: A1.12 (GPIO9), SW6.1, SW20.1, SW34.1, SW47.1, SW59.1
/COL2: A1.14 (GPIO10), SW7.1, SW21.1, SW35.1, SW48.1, SW60.1
/COL3: A1.15 (GPIO11), SW8.1, SW22.1, SW36.1, SW49.1, SW61.1
/COL4: A1.16 (GPIO12), SW9.1, SW23.1, SW37.1, SW50.1, SW62.1
/COL5: A1.17 (GPIO13), SW10.1, SW24.1, SW38.1, SW51.1, SW63.1
/COL8: A1.21 (GPIO16), SW4.1, SW13.1, SW27.1, SW41.1, SW54.1
/COL9: A1.22 (GPIO17), SW14.1, SW28.1, SW42.1, SW55.1
/COL10: A1.24 (GPIO18), SW15.1, SW29.1, SW43.1, SW56.1
/COL11: A1.25 (GPIO19), SW16.1, SW30.1, SW44.1, SW57.1
/COL12: A1.29 (GPIO22), SW17.1, SW31.1, SW45.1
/COL13: A1.31 (GPIO26_ADC0), SW18.1, SW32.1, SW65.S1
/ROW0: A1.2 (GPIO1), D1.1 (K)
/ROW1: A1.4 (GPIO2), D80.1 (K), D81.1 (K), D82.1 (K), D143.1 (K)
/ROW2: A1.5 (GPIO3), D83.1 (K), D84.1 (K), D85.1 (K), D86.1 (K), D87.1 (K), D88.1 (K), D89.1 (K), D90.1 (K), D91.1 (K), D92.1 (K), D93.1 (K), D94.1 (K), D95.1 (K), D96.1 (K)
/ROW3: A1.6 (GPIO4), D97.1 (K), D98.1 (K), D99.1 (K), D100.1 (K), D101.1 (K), D102.1 (K), D103.1 (K), D104.1 (K), D105.1 (K), D106.1 (K), D107.1 (K), D108.1 (K), D109.1 (K), D110.1 (K)
/ROW4: A1.7 (GPIO5), D111.1 (K), D112.1 (K), D113.1 (K), D114.1 (K), D115.1 (K), D116.1 (K), D117.1 (K), D118.1 (K), D119.1 (K), D120.1 (K), D121.1 (K), D122.1 (K), D123.1 (K)
/ROW5: A1.9 (GPIO6), D124.1 (K), D125.1 (K), D126.1 (K), D127.1 (K), D128.1 (K), D129.1 (K), D130.1 (K), D131.1 (K), D132.1 (K), D133.1 (K), D134.1 (K), D135.1 (K)
/ROW6: A1.10 (GPIO7), D136.1 (K), D137.1 (K), D138.1 (K), D139.1 (K), D140.1 (K), D141.1 (K), D142.1 (K), D144.1 (K)
unnamed: A1.36 (3V3), U1.2 (VCC)
unnamed: A1.1 (GPIO0), R1.2
unnamed: A1.26 (GPIO20), U1.4 (SDA)
unnamed: A1.27 (GPIO21), U1.3 (SCL)
unnamed: A1.32 (GPIO27_ADC1), SW65.A
unnamed: A1.34 (GPIO28_ADC2), SW65.B
unnamed 25: A1.40 (VBUS), C1.1, C2.1, C3.1, C4.1, C5.1, C6.1, C7.1, C8.1, C9.1, C10.1, C11.1, C12.1, C13.1, C14.1, C16.1, C17.1, C18.1, C19.1, C20.1, C21.1, C22.1, C23.1, C24.1, C25.1, C26.1, C27.1, C28.1, C29.1, C31.1, C32.1, C33.1, C34.1, C35.1, C36.1, C37.1, C38.1, C39.1, C40.1, C41.1, C42.1, C43.1, C47.1, C48.1, C49.1, C50.1, C51.1, C52.1, C53.1, C54.1, C55.1, C56.1, C57.1, C58.1, C62.1, C63.1, C64.1, C65.1, C66.1, C67.1, C68.1, C69.1, C70.1, C71.1, C74.1, C75.1, C76.1, C77.1, D2.3 (VDD), D3.3 (VDD), D4.3 (VDD), D5.3 (VDD), D6.3 (VDD), D7.3 (VDD), D8.3 (VDD), D9.3 (VDD), D10.3 (VDD), D11.3 (VDD), D12.3 (VDD), D13.3 (VDD), D14.3 (VDD), D15.3 (VDD), D17.3 (VDD), D18.3 (VDD), D19.3 (VDD), D20.3 (VDD), D21.3 (VDD), D22.3 (VDD), D23.3 (VDD), D24.3 (VDD), D25.3 (VDD), D26.3 (VDD), D27.3 (VDD), D28.3 (VDD), D29.3 (VDD), D30.3 (VDD), D32.3 (VDD), D33.3 (VDD), D34.3 (VDD), D35.3 (VDD), D36.3 (VDD), D37.3 (VDD), D38.3 (VDD), D39.3 (VDD), D40.3 (VDD), D41.3 (VDD), D42.3 (VDD), D43.3 (VDD), D44.3 (VDD), D48.3 (VDD), D49.3 (VDD), D50.3 (VDD), D51.3 (VDD), D52.3 (VDD), D53.3 (VDD), D54.3 (VDD), D55.3 (VDD), D56.3 (VDD), D57.3 (VDD), D58.3 (VDD), D59.3 (VDD), D63.3 (VDD), D64.3 (VDD), D65.3 (VDD), D66.3 (VDD), D67.3 (VDD), D68.3 (VDD), D69.3 (VDD), D70.3 (VDD), D71.3 (VDD), D72.3 (VDD), D76.3 (VDD), D77.3 (VDD), D78.3 (VDD), D79.3 (VDD); also elsewhere on the board
unnamed: D1.2 (A), SW1.2
unnamed: D2.2 (DIN), D78.4 (DOUT)
unnamed: D2.4 (DOUT), D3.2 (DIN)
unnamed: D3.4 (DOUT), D4.2 (DIN)
unnamed: D4.4 (DOUT), D5.2 (DIN)
unnamed: D5.4 (DOUT), D6.2 (DIN)
unnamed: D6.4 (DOUT), D7.2 (DIN)
unnamed: D7.4 (DOUT), D8.2 (DIN)
unnamed: D8.4 (DOUT), D9.2 (DIN)
unnamed: D9.4 (DOUT), D10.2 (DIN)
unnamed: D10.4 (DOUT), D11.2 (DIN)
unnamed 37: A1.3 (GND), A1.8 (GND), A1.13 (GND), A1.18 (GND), A1.23 (GND), A1.28 (GND), A1.38 (GND), C1.2, C2.2, C3.2, C4.2, C5.2, C6.2, C7.2, C8.2, C9.2, C10.2, C11.2, C12.2, C13.2, C14.2, C16.2, C17.2, C18.2, C19.2, C20.2, C21.2, C22.2, C23.2, C24.2, C25.2, C26.2, C27.2, C28.2, C29.2, C31.2, C32.2, C33.2, C34.2, C35.2, C36.2, C37.2, C38.2, C39.2, C40.2, C41.2, C42.2, C43.2, C47.2, C48.2, C49.2, C50.2, C51.2, C52.2, C53.2, C54.2, C55.2, C56.2, C57.2, C58.2, C62.2, C63.2, C64.2, C65.2, C66.2, C67.2, C68.2, C69.2, C70.2, C71.2, C74.2, C75.2, C76.2, C77.2, D2.1 (VSS), D3.1 (VSS), D4.1 (VSS), D5.1 (VSS), D6.1 (VSS), D7.1 (VSS), D8.1 (VSS), D9.1 (VSS), D10.1 (VSS), D11.1 (VSS), D12.1 (VSS), D13.1 (VSS), D14.1 (VSS), D15.1 (VSS), D17.1 (VSS), D18.1 (VSS), D19.1 (VSS), D20.1 (VSS), D21.1 (VSS), D22.1 (VSS), D23.1 (VSS), D24.1 (VSS), D25.1 (VSS), D26.1 (VSS), D27.1 (VSS), D28.1 (VSS), D29.1 (VSS), D30.1 (VSS), D32.1 (VSS), D33.1 (VSS), D34.1 (VSS), D35.1 (VSS), D36.1 (VSS), D37.1 (VSS), D38.1 (VSS), D39.1 (VSS), D40.1 (VSS), D41.1 (VSS), D42.1 (VSS), D43.1 (VSS), D44.1 (VSS), D48.1 (VSS), D49.1 (VSS), D50.1 (VSS), D51.1 (VSS), D52.1 (VSS), D53.1 (VSS), D54.1 (VSS), D55.1 (VSS), D56.1 (VSS), D57.1 (VSS), D58.1 (VSS), D59.1 (VSS), D63.1 (VSS), D64.1 (VSS), D65.1 (VSS), D66.1 (VSS), D67.1 (VSS), D68.1 (VSS), D69.1 (VSS), D70.1 (VSS), D71.1 (VSS), D72.1 (VSS), D76.1 (VSS), D77.1 (VSS), D78.1 (VSS), D79.1 (VSS), SW65.C, U1.1 (GND); also elsewhere on the board
unnamed: D11.4 (DOUT), D12.2 (DIN)
unnamed: D12.4 (DOUT), D13.2 (DIN)
unnamed: D13.4 (DOUT), D14.2 (DIN)
unnamed: D14.4 (DOUT), D15.2 (DIN)
unnamed: D15.4 (DOUT), D17.2 (DIN)
unnamed: D17.4 (DOUT), D18.2 (DIN)
unnamed: D18.4 (DOUT), D19.2 (DIN)
unnamed: D19.4 (DOUT), D20.2 (DIN)
unnamed: D20.4 (DOUT), D21.2 (DIN)
unnamed: D21.4 (DOUT), D22.2 (DIN)
unnamed: D22.4 (DOUT), D23.2 (DIN)
unnamed: D23.4 (DOUT), D24.2 (DIN)
unnamed: D24.4 (DOUT), D25.2 (DIN)
unnamed: D25.4 (DOUT), D26.2 (DIN)
unnamed: D26.4 (DOUT), D27.2 (DIN)
unnamed: D27.4 (DOUT), D28.2 (DIN)
unnamed: D28.4 (DOUT), D29.2 (DIN)
unnamed: D29.4 (DOUT), D30.2 (DIN)
unnamed: D30.4 (DOUT), D32.2 (DIN)
unnamed: D32.4 (DOUT), D33.2 (DIN)
unnamed: D33.4 (DOUT), D34.2 (DIN)
unnamed: D34.4 (DOUT), D35.2 (DIN)
unnamed: D35.4 (DOUT), D36.2 (DIN)
unnamed: D36.4 (DOUT), D37.2 (DIN)
unnamed: D37.4 (DOUT), D38.2 (DIN)
unnamed: D38.4 (DOUT), D39.2 (DIN)
unnamed: D39.4 (DOUT), D40.2 (DIN)
unnamed: D40.4 (DOUT), D41.2 (DIN)
unnamed: D41.4 (DOUT), D42.2 (DIN)
unnamed: D42.4 (DOUT), D43.2 (DIN)
unnamed: D43.4 (DOUT), D44.2 (DIN)
unnamed: D44.4 (DOUT), D48.2 (DIN)
unnamed: D48.4 (DOUT), D49.2 (DIN)
unnamed: D49.4 (DOUT), D50.2 (DIN)
unnamed: D50.4 (DOUT), D51.2 (DIN)
unnamed: D51.4 (DOUT), D52.2 (DIN)
unnamed: D52.4 (DOUT), D53.2 (DIN)
unnamed: D53.4 (DOUT), D54.2 (DIN)
unnamed: D54.4 (DOUT), D55.2 (DIN)
unnamed: D55.4 (DOUT), D56.2 (DIN)
unnamed: D56.4 (DOUT), D57.2 (DIN)
unnamed: D57.4 (DOUT), D58.2 (DIN)
unnamed: D58.4 (DOUT), D59.2 (DIN)
unnamed: D59.4 (DOUT), D63.2 (DIN)
unnamed: D63.4 (DOUT), D64.2 (DIN)
unnamed: D64.4 (DOUT), D65.2 (DIN)
unnamed: D65.4 (DOUT), D66.2 (DIN)
unnamed: D66.4 (DOUT), D67.2 (DIN)
unnamed: D67.4 (DOUT), D68.2 (DIN)
unnamed: D68.4 (DOUT), D69.2 (DIN)
unnamed: D69.4 (DOUT), D70.2 (DIN)
unnamed: D70.4 (DOUT), D71.2 (DIN)
unnamed: D71.4 (DOUT), D72.2 (DIN)
unnamed: D76.2 (DIN), D79.4 (DOUT)
unnamed: D76.4 (DOUT), D77.2 (DIN)
unnamed: D77.4 (DOUT), D78.2 (DIN)
unnamed: D79.2 (DIN), R1.1
unnamed: D80.2 (A), SW2.2
unnamed: D81.2 (A), SW3.2
unnamed: D82.2 (A), SW4.2
unnamed: D83.2 (A), SW5.2
unnamed: D84.2 (A), SW6.2
unnamed: D85.2 (A), SW7.2
unnamed: D86.2 (A), SW8.2
unnamed: D87.2 (A), SW9.2
unnamed: D88.2 (A), SW10.2
unnamed: D89.2 (A), SW11.2
unnamed: D90.2 (A), SW12.2
unnamed: D91.2 (A), SW13.2
unnamed: D92.2 (A), SW14.2
unnamed: D93.2 (A), SW15.2
unnamed: D94.2 (A), SW16.2
unnamed: D95.2 (A), SW17.2
unnamed: D96.2 (A), SW18.2
unnamed: D97.2 (A), SW19.2
unnamed: D98.2 (A), SW20.2
unnamed: D99.2 (A), SW21.2
unnamed: D100.2 (A), SW22.2
unnamed: D101.2 (A), SW23.2
unnamed: D102.2 (A), SW24.2
unnamed: D103.2 (A), SW25.2
unnamed: D104.2 (A), SW26.2
unnamed: D105.2 (A), SW27.2
unnamed: D106.2 (A), SW28.2
unnamed: D107.2 (A), SW29.2
unnamed: D108.2 (A), SW30.2
unnamed: D109.2 (A), SW31.2
unnamed: D110.2 (A), SW32.2
unnamed: D111.2 (A), SW33.2
unnamed: D112.2 (A), SW34.2
unnamed: D113.2 (A), SW35.2
unnamed: D114.2 (A), SW36.2
unnamed: D115.2 (A), SW37.2
unnamed: D116.2 (A), SW38.2
unnamed: D117.2 (A), SW39.2
unnamed: D118.2 (A), SW40.2
unnamed: D119.2 (A), SW41.2
unnamed: D120.2 (A), SW42.2
unnamed: D121.2 (A), SW43.2
unnamed: D122.2 (A), SW44.2
unnamed: D123.2 (A), SW45.2
unnamed: D124.2 (A), SW46.2
unnamed: D125.2 (A), SW47.2
unnamed: D126.2 (A), SW48.2
unnamed: D127.2 (A), SW49.2
unnamed: D128.2 (A), SW50.2
unnamed: D129.2 (A), SW51.2
unnamed: D130.2 (A), SW52.2
unnamed: D131.2 (A), SW53.2
unnamed: D132.2 (A), SW54.2
unnamed: D133.2 (A), SW55.2
unnamed: D134.2 (A), SW56.2
unnamed: D135.2 (A), SW57.2
unnamed: D136.2 (A), SW58.2
unnamed: D137.2 (A), SW59.2
unnamed: D138.2 (A), SW60.2
unnamed: D139.2 (A), SW61.2
unnamed: D140.2 (A), SW62.2
unnamed: D141.2 (A), SW63.2
unnamed: D142.2 (A), SW64.2
unnamed: D143.2 (A), SW65.S2
unnamed: D144.2 (A), SW66.2

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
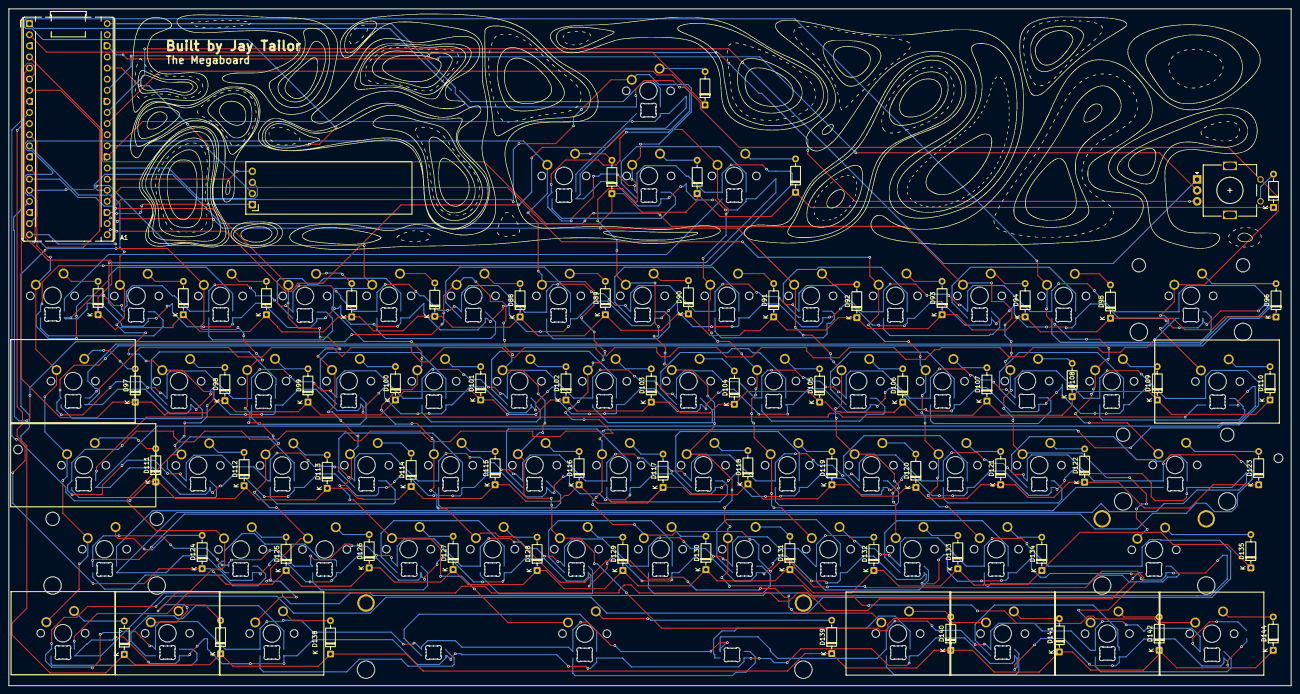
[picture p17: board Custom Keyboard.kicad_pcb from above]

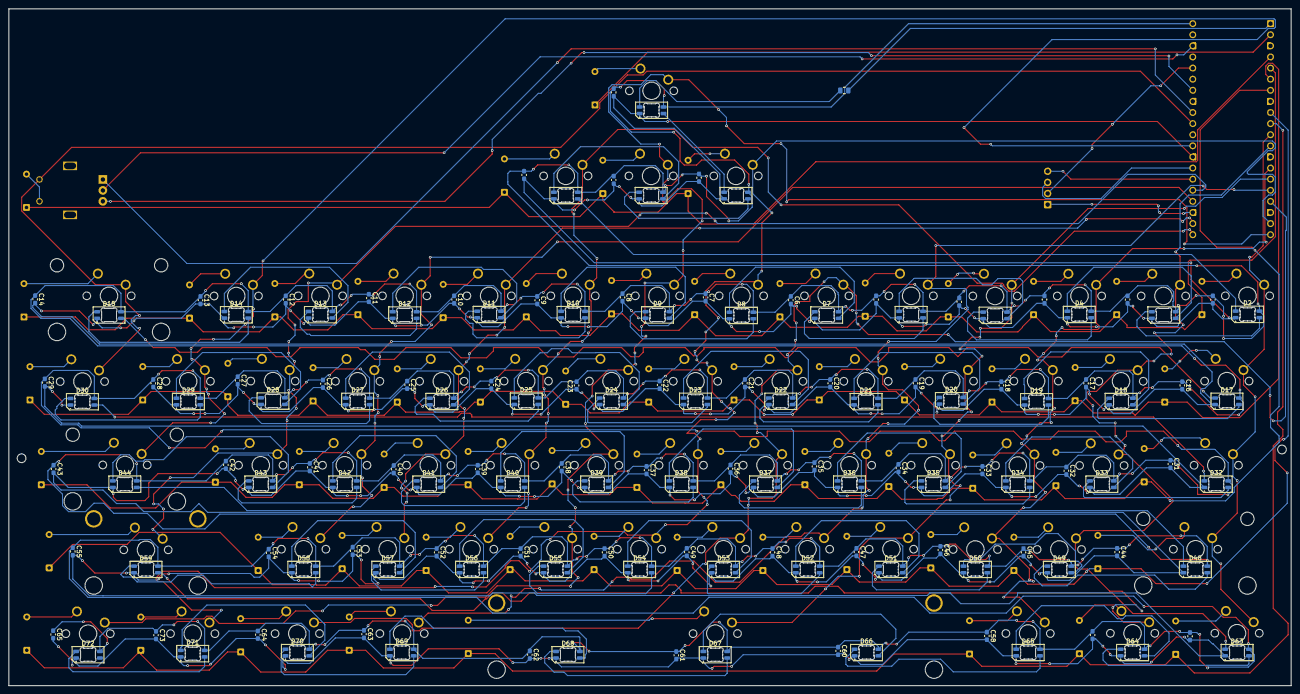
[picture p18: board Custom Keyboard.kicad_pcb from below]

Board: 2 copper layers, 293.2 x 154.8 mm, 274 parts (135 on the bottom side), 162 nets.

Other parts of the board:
C44, C45, C46, C60, C61, C73: C; C_0603_1608Metric_Pad1.08x0.95mm_HandSolder

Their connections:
unnamed 25: C44.1, C45.1, C46.1, C60.1, C61.1, C73.1; also elsewhere on the board
unnamed 37: C44.2, C45.2, C46.2, C60.2, C61.2, C73.2; also elsewhere on the board

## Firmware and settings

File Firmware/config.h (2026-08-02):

#pragma once

#define MATRIX_ROWS 7
#define MATRIX_COLS 14

#define MATRIX_ROWS_PINS {GP1, GP2, GP3, GP4, GP5, GP6, GP7}
#define MATRIX_COLS_PINS {GP8, GP9, GP10, GP11, GP12, GP13, GP14, GP15, GP16, GP17, GP18, GP19, GP22, GP26}

#define WS2812_DI_PIN GP0
#define RGB_MATRIX_LED_COUNT 67
#define ENABLE_RGB_MATRIX_SOLID_REACTIVE_SIMPLE
#define RGB_MATRIX_DEFAULT_MODE RGB_MATRIX_SOLID_REACTIVE_SIMPLE
#define RGB_MATRIX_DEFAULT_HUE 170
#define RGB_MATRIX_DEFAULT_SAT 255
#define RGB_MATRIX_DEFAULT_VAL 180
#define RGB_MATRIX_DEFAULT_SPD 127
#define OLED_DISPLAY_128X32
#define OLED_TIMEOUT 300000
#define OLED_BRIGHTNESS 128
#define I2C_DRIVER I2CD1
#define I2C1_SCL_PIN GP21
#define I2C1_SDA_PIN GP20

#define ENCODER_A_PINS {GP27}
#define ENCODER_B_PINS {GP28}
#define ENCODER_RESOLUTION 20

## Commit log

2026-07-03 init schematic
2026-07-03 Add schematic files
2026-07-03 Add schematic timelapse
    init
2026-07-31 Rename journaling/final pcb/image_1.png to journaling/major updates/final pcb/image_1.png
2026-07-31 Rename journaling/final pcb/image_2.png to journaling/major updates/final pcb/image_2.png
2026-07-31 Rename journaling/final pcb/readme.md to journaling/major updates/final pcb/readme.md
2026-07-31 Rename journaling/shematic/Screenshot.jpg to journaling/major updates/schematic/Screenshot.jpg
2026-07-31 Rename journaling/shematic/readme.md to journaling/major updates/schematic/readme.md
2026-08-02 Add cad model
    For readme.md
2026-08-02 Add PCB Schematic
    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
2026-08-02 Add PCB Design
    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
2026-08-02 Add KiCad files
    [Custom Keyboard.kicad_pcb, Custom Keyboard.kicad_sch]
2026-08-23 New PCB ss for ReadMe with updates
